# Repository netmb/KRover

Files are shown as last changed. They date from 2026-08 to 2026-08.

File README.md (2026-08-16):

# KRover

Dieses Projekt realisiert ein GNSS-RTK-Rover-System für rund 150 €.

KRover dient zur Anzeige von Flurstücken, zur Navigation zu Grenzpunkten und
zur Aufnahme eigener Punkte, Strecken, Flächen und relativer Höhen. Das System
besteht aus einer nativen iOS-App und einem ESP32-S3-basierten Rover mit
Quectel-LG290P-Empfänger und Neigungssensor.

Die App lädt Karten- und Flurstücksdaten, empfängt SAPOS-Korrekturdaten über
NTRIP und kommuniziert bidirektional per Bluetooth Low Energy (BLE) mit der
Rover-Hardware. RTCM-Korrekturen laufen von der App über BLE und UART zum
LG290P; GNSS-, IMU- und Statusdaten werden in Gegenrichtung an die App
übertragen.

<table>
  <tr>
    <td align="center" valign="top" width="33%">
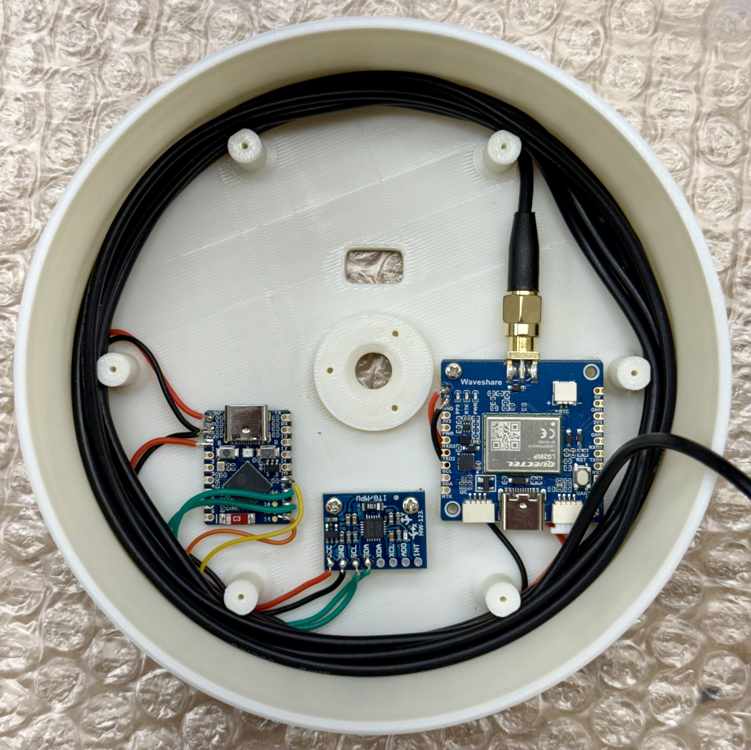
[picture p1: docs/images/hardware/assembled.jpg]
ESP32-S3-Zero, LG290P und GY-521 im KRover-Gehäuse
      
    </td>
    <td align="center" valign="top" width="33%">
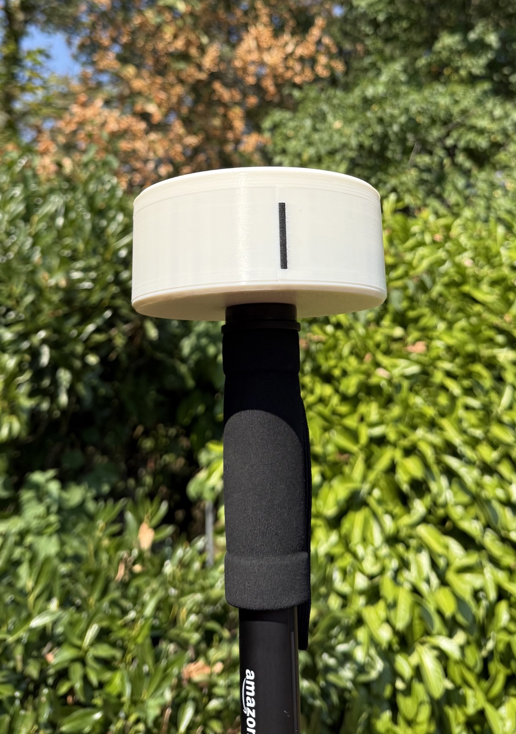
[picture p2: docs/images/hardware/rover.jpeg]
Fertiger KRover auf einem Einhandstativ
      
    </td>
    <td align="center" valign="top" width="33%">
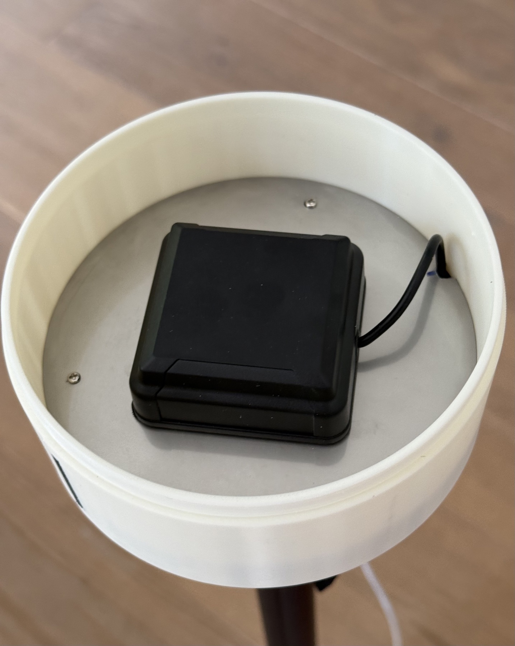
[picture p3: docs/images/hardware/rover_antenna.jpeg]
Mehrband-GNSS-Antenne im geöffneten KRover-Gehäuse
      
    </td>
  </tr>
</table>

<p align="center">
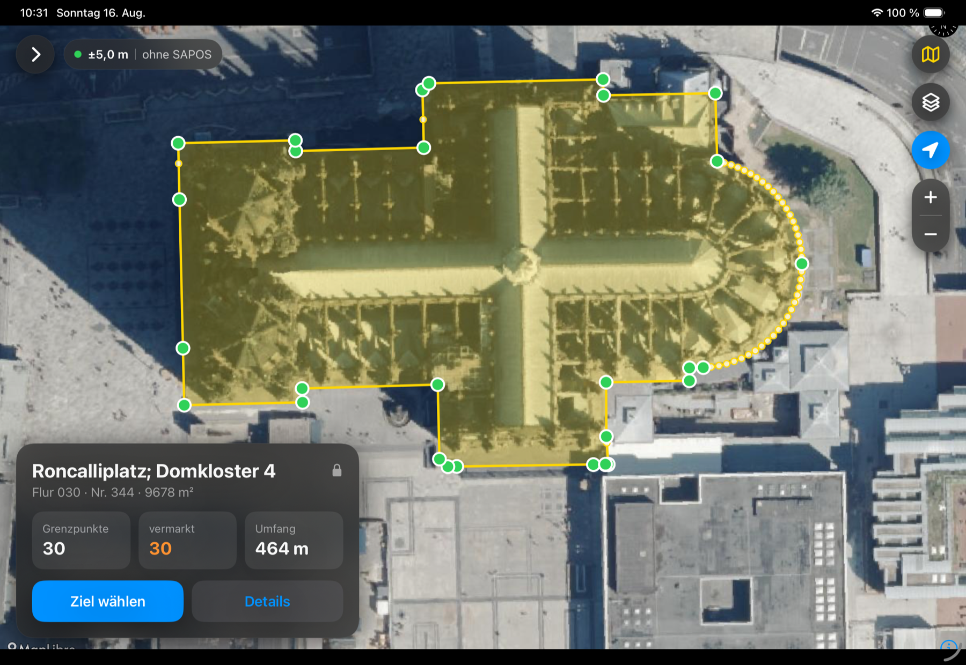
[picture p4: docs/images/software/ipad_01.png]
Flurstücksansicht der KRover-App auf einem iPad
  
</p>
<p align="center">
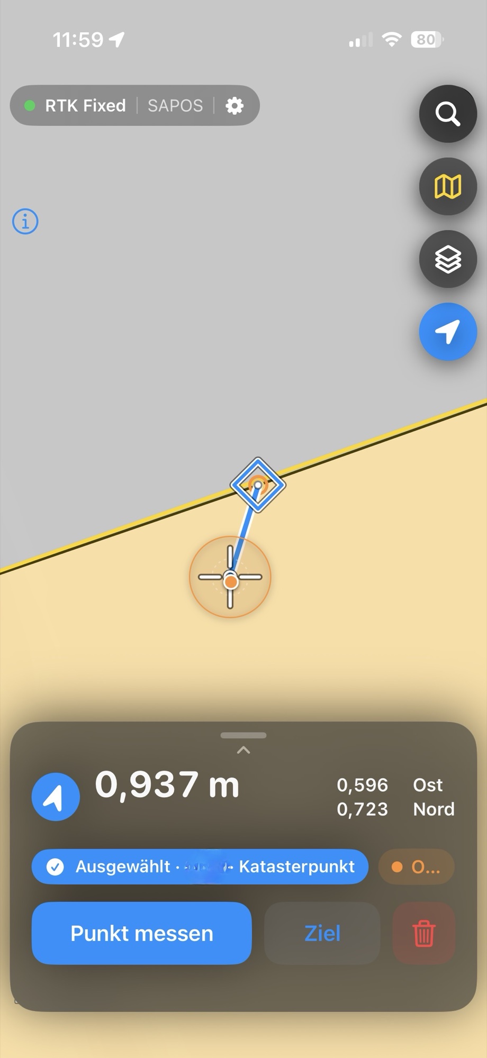
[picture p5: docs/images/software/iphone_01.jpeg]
Navigation zu einem Katasterpunkt in der KRover-App
  
  &nbsp;&nbsp;&nbsp;
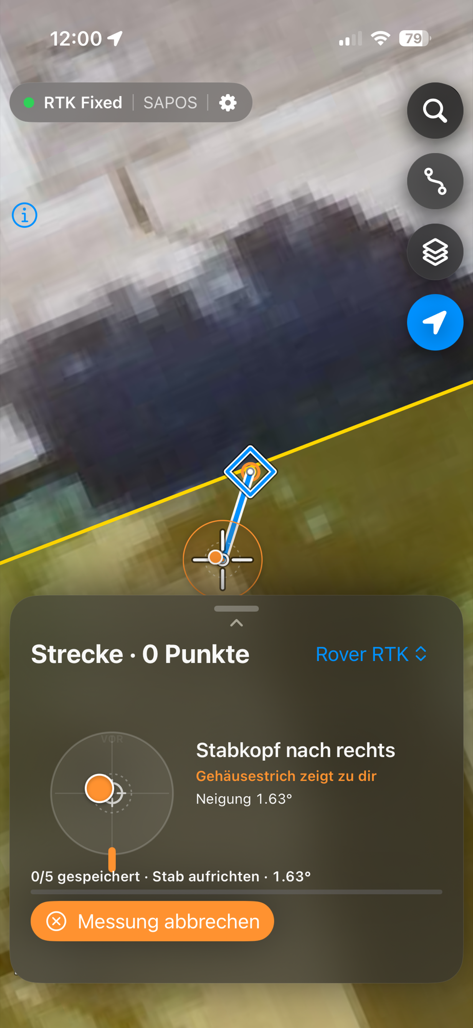
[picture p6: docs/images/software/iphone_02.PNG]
Streckenmessung mit Neigungsführung in der KRover-App
  
</p>

## Benötigte Hardware

<table>
  <tr>
    <td align="center" width="33%">
      <strong>ESP</strong><br>
      Waveshare ESP32-S3-Zero<br><br>
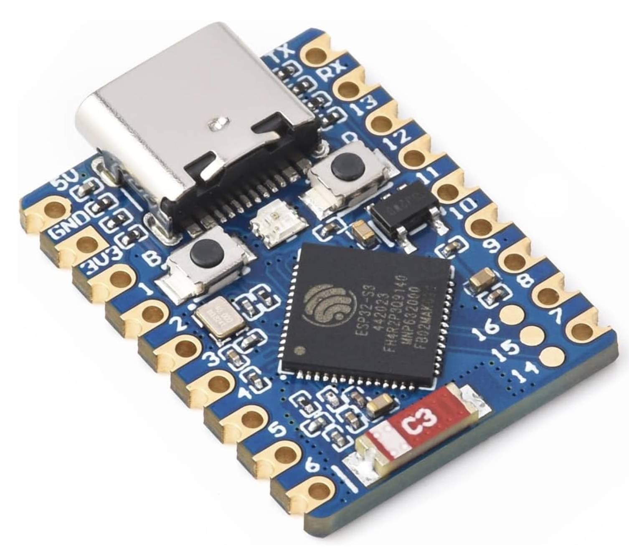
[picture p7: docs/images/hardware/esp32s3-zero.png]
Waveshare ESP32-S3-Zero
      
    </td>
    <td align="center" width="33%">
      <strong>GNSS-Empfänger</strong><br>
      Waveshare LG290P<br>mit Quectel LG290P<br><br>
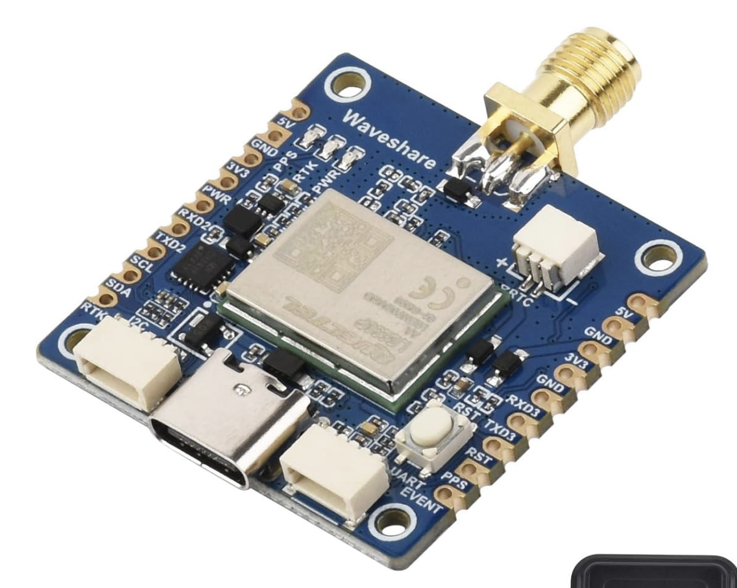
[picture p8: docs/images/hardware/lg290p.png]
Waveshare LG290P
      
    </td>
    <td align="center" width="33%">
      <strong>GNSS-Antenne</strong><br>
      GPS L1/L2/L5 · BeiDou B1C/B2a/B3<br>
      GLONASS G1/G2/G3 · Galileo E1/E5/E6<br>
      QZSS · SBAS<br><br>
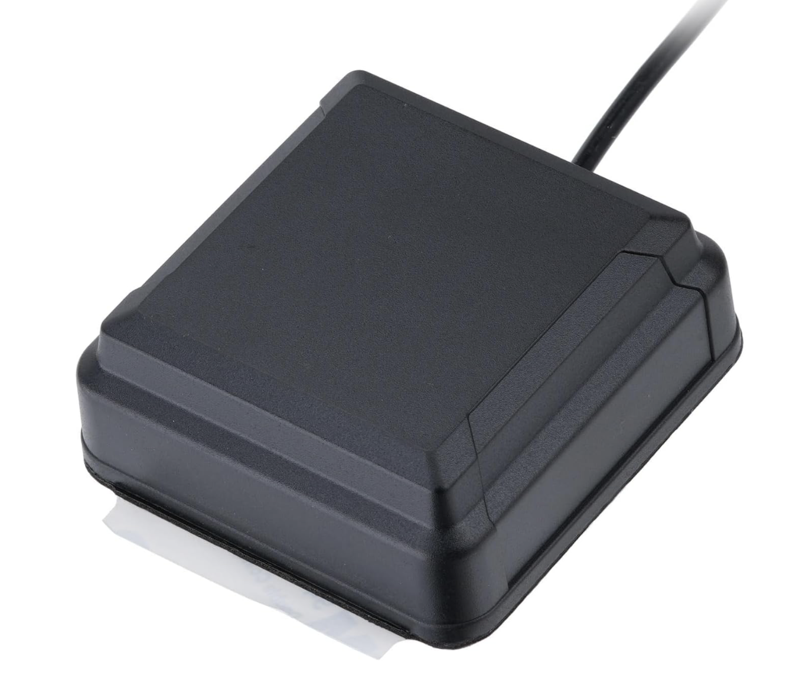
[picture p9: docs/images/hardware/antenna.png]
Aktive Mehrband-GNSS-Antenne
      
    </td>
  </tr>
  <tr>
    <td align="center" width="33%">
      <strong>Neigungssensor</strong><br>
      GY-521 mit MPU-6050<br><br>
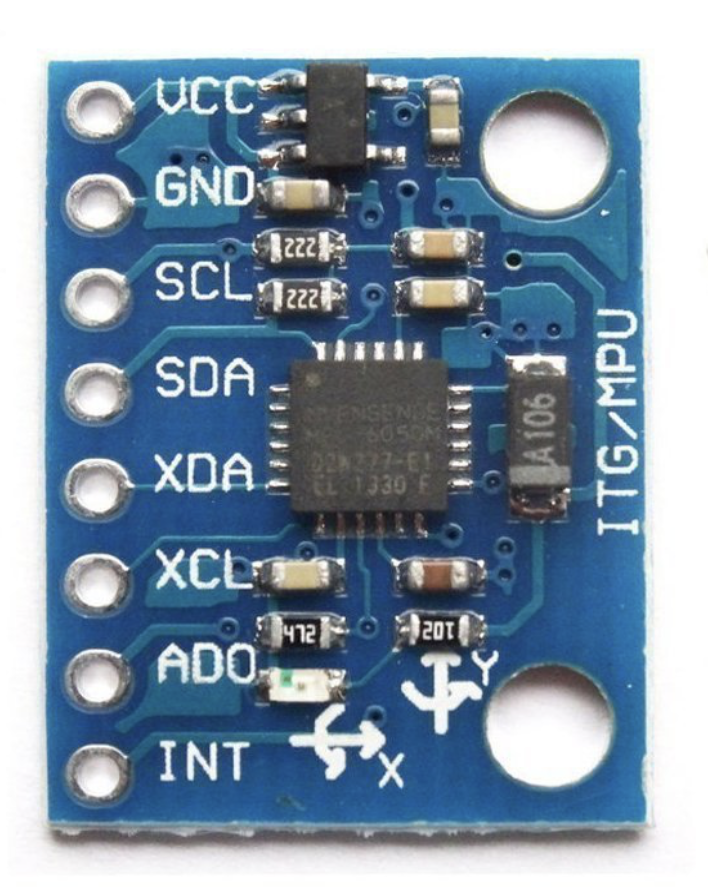
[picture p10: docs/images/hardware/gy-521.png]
GY-521 mit MPU-6050
      
    </td>
    <td align="center" width="33%">
      <strong>Einhandstativ</strong><br>
      1/4-Zoll-Standard-Fotogewinde<br>mit Schraubplatte<br><br>
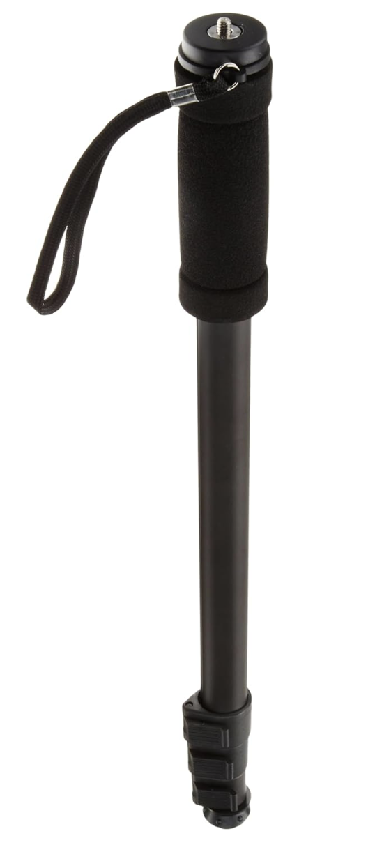
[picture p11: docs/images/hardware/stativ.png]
Einhandstativ
      
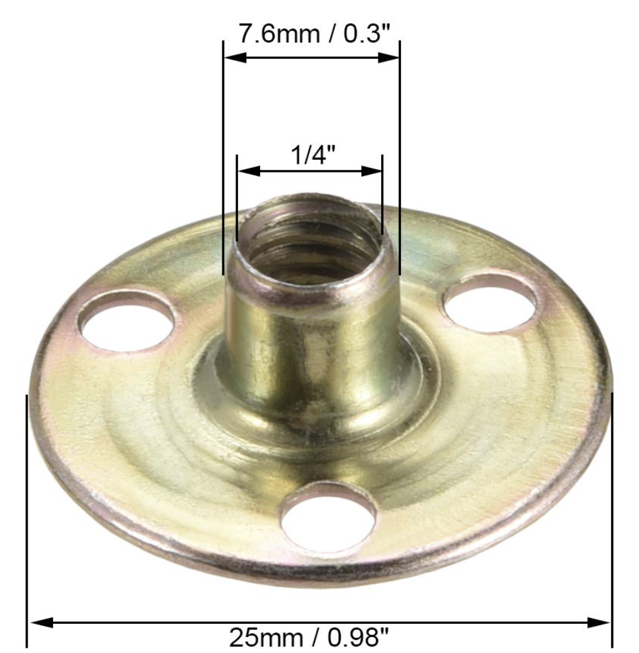
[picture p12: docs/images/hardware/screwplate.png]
Schraubplatte mit 1/4-Zoll-Gewinde
      
    </td>
    <td align="center" width="33%">
      <strong>Stahl-/Edelstahlronde</strong><br>
      1 mm Stärke<br>
      120 mm Durchmesser<br><br>
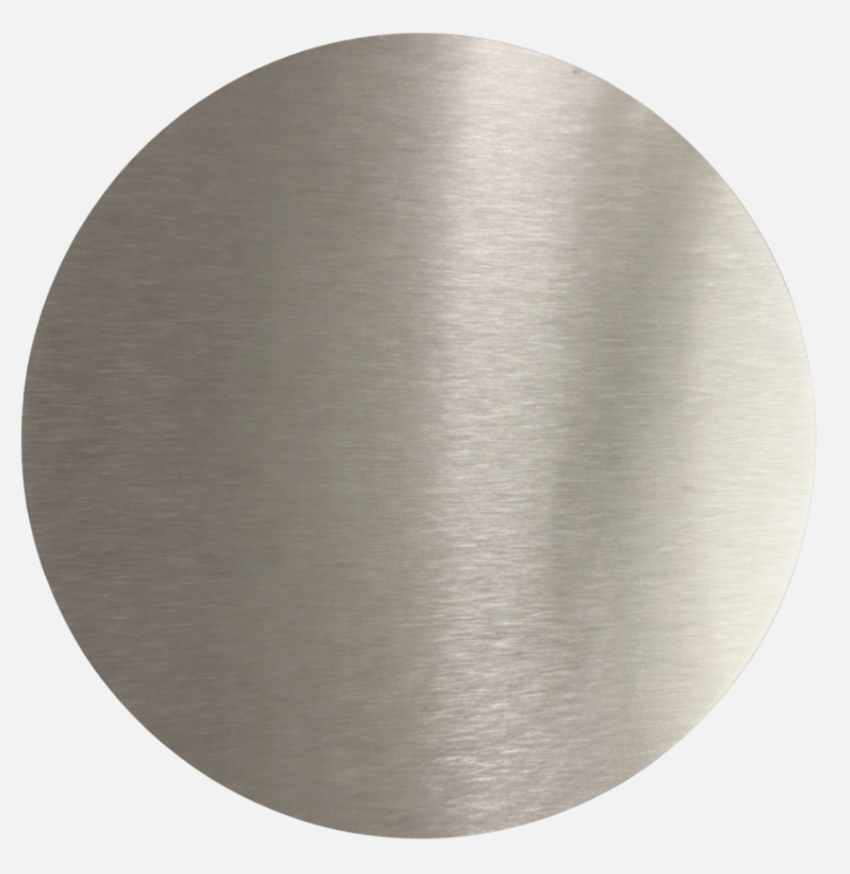
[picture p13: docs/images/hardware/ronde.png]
Stahl- oder Edelstahlronde
      
    </td>
  </tr>
</table>

Die Druckdatei für das Gehäuse liegt unter
[`case/case.3mf`](case/case.3mf).

## Hardware anschließen

### GY-521 mit ESP32-S3 verbinden

| GY-521 | ESP32-S3-Zero | Funktion |
|---|---|---|
| `VCC` | `3V3` | Versorgung mit 3,3 V |
| `GND` | `GND` | Gemeinsame Masse |
| `SDA` | `GPIO 8` | I²C-Daten |
| `SCL` | `GPIO 9` | I²C-Takt |

Die Firmware erkennt den MPU-6050 an `0x68` oder `0x69`. Wird kein Sensor
gefunden, aktiviert sie automatisch den integrierten IMU-Simulator.

### LG290P mit ESP32-S3 verbinden

| LG290P | ESP32-S3-Zero | Funktion |
|---|---|---|
| `TX` | `GPIO 7` (`RX`) | NMEA-/PQTM-Daten vom LG290P |
| `RX` | `GPIO 10` (`TX`) | RTCM-Korrekturdaten zum LG290P |
| `GND` | `GND` | Gemeinsame Masse |

Die UART-Verbindung verwendet `460800 Baud`, `8N1`.

## Repository installieren

```sh
git clone https://github.com/netmb/KRover.git
cd KRover
```

## ESP32-Firmware installieren

### Voraussetzungen

- [PlatformIO Core](https://docs.platformio.org/en/latest/core/installation/index.html)
  oder Visual Studio Code mit der PlatformIO-Erweiterung
- Waveshare ESP32-S3-Zero und ein USB-Datenkabel
- angeschlossene Rover-Hardware gemäß den Tabellen oben

### Firmware bauen und übertragen

1. ESP32-S3-Zero per USB mit dem Mac oder PC verbinden.
2. In das Firmware-Verzeichnis wechseln.
3. Firmware bauen und auf das Board übertragen.
4. Den seriellen Monitor öffnen und den Start kontrollieren.

```sh
cd firmware
pio run -e waveshare-esp32-s3-zero
pio run -e waveshare-esp32-s3-zero -t upload
pio device monitor --baud 115200
```

Falls PlatformIO den Upload-Port nicht automatisch erkennt, kann er explizit
angegeben werden:

```sh
pio run -e waveshare-esp32-s3-zero -t upload \
  --upload-port /dev/cu.usbmodemXXXX
```

Nach erfolgreichem Start erscheint der Rover als BLE-Gerät `KRover-XXXX`. Die
letzten vier Zeichen werden aus der MAC-Adresse des ESP32 gebildet. Die aktuelle
Konfiguration in [`firmware/platformio.ini`](firmware/platformio.ini) verwendet
den echten LG290P (`KATASTER_GNSS_SIMULATION=0`).

### Firmware testen

```sh
cd firmware
pio test -e native
pio run -e waveshare-esp32-s3-zero
```

## iOS-App installieren

### Voraussetzungen

- macOS mit Xcode 26 oder neuer
- [XcodeGen](https://github.com/yonaskolb/XcodeGen)
- iPhone oder iPad mit iOS 17 oder neuer
- Apple-Development-Team für die Installation auf einem echten Gerät

XcodeGen kann beispielsweise mit Homebrew installiert werden:

```sh
brew install xcodegen
```

### Xcode-Projekt erzeugen

Das Xcode-Projekt wird aus [`ios/project.yml`](ios/project.yml) generiert und
nicht im Repository gespeichert:

```sh
cd ios
xcodegen generate
open KRover.xcodeproj
```

### App auf iPhone oder iPad installieren

1. In Xcode das Projekt `KRover` und das Target `KRover` auswählen.
2. Unter **Signing & Capabilities** das eigene Development-Team eintragen.
3. Das angeschlossene iPhone oder iPad als Zielgerät auswählen.
4. Das Scheme `KRover` starten (`⌘R`).
5. Auf dem Gerät den Zugriff auf Bluetooth und den Standort erlauben.
6. In der App den Rover `KRover-XXXX` auswählen und verbinden.
7. SAPOS-Zugangsdaten in der App hinterlegen und die NTRIP-Verbindung starten.

SAPOS-Zugangsdaten werden im iOS-Schlüsselbund gespeichert. Ein physisches
iPhone oder iPad ist für die BLE-Verbindung erforderlich; der iOS-Simulator
kann für UI-Entwicklung und Tests verwendet werden.

Falls die Bundle-ID mit dem eigenen Development-Team kollidiert, muss
`PRODUCT_BUNDLE_IDENTIFIER` in [`ios/project.yml`](ios/project.yml) angepasst
und das Projekt anschließend erneut mit `xcodegen generate` erzeugt werden.

### iOS-Tests ausführen

```sh
cd ios
xcodegen generate
xcodebuild -project KRover.xcodeproj \
  -scheme KRover \
  -destination 'platform=iOS Simulator,name=iPhone 17 Pro' \
  test
```

Die Tests mit dem live NRW-Katasterdienst werden ohne fest eingechecktes
Flurstück übersprungen. Für einen lokalen Integrationstest kann ein eigenes
Test-Flurstück ausschließlich für den Prozess gesetzt werden:

```sh
KROVER_INTEGRATION_PARCEL_ID='...' xcodebuild -project KRover.xcodeproj \
  -scheme KRover \
  -destination 'platform=iOS Simulator,name=iPhone 17 Pro' \
  test
```

Das BLE-Datenformat und die verwendeten Characteristics sind in
[`docs/ble-protocol.md`](docs/ble-protocol.md) dokumentiert.

## Lizenz

KRover ist unter der
[PolyForm Noncommercial License 1.0.0](LICENSE) verfügbar. Private und andere
nichtkommerzielle Nutzung ist im Rahmen dieser Lizenz erlaubt. Kommerzielle
oder gewerbliche Nutzung erfordert vorab eine separate schriftliche Lizenz von
[`netmb`](https://github.com/netmb).

Das Projekt ist damit öffentlich einsehbar (source available), aber keine Open-
Source-Software im Sinne der OSI-Definition.

Abhängigkeiten und sonstiges Material Dritter sind davon ausgenommen und
behalten ihre jeweiligen Lizenzen. Details stehen in den
[Drittanbieter-Hinweisen](THIRD_PARTY_NOTICES.md). Bei der Weitergabe
kompilierter App- oder Firmware-Binaries müssen zusätzlich die dort genannten
Lizenzbedingungen erfüllt werden.

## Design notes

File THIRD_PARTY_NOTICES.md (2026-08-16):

# Drittanbieter-Hinweise

Die PolyForm-Noncommercial-Lizenz von KRover gilt nicht für Software und
sonstiges Material Dritter. Diese Bestandteile behalten ihre eigenen Lizenzen.
Das Repository enthält keine Kopien der nachfolgend genannten Bibliotheken;
sie werden beim Build über Swift Package Manager beziehungsweise PlatformIO
bezogen.

## Laufzeit-Abhängigkeiten

- **MapLibre Native 6.28.0** — BSD 2-Clause. Copyright MapLibre contributors,
  MapTiler.com und Mapbox. Die Lizenz und die Copyright-Hinweise müssen bei der
  Weitergabe der iOS-App in der Dokumentation oder in anderen mitgelieferten
  Materialien erhalten bleiben.
  [Lizenz](https://github.com/maplibre/maplibre-gl-native-distribution/blob/6.28.0/LICENSE.md)
- **NimBLE-Arduino 2.5.1** — Apache License 2.0. Copyright Ryan Powell sowie die
  Mitwirkenden von esp-nimble-cpp und NimBLE-Arduino; Teile gehen auf Neil
  Kolban und esp32-snippets zurück. Bei einer Firmware-Weitergabe sind die
  Apache-Lizenz und die NOTICE-Hinweise beizulegen.
  [Lizenz](https://github.com/h2zero/NimBLE-Arduino/blob/2.5.1/LICENSE) ·
  [NOTICE](https://github.com/h2zero/NimBLE-Arduino/blob/2.5.1/NOTICE)
- **Arduino-ESP32 2.0.17** — GNU Lesser General Public License 2.1 oder später.
  Die Version wird durch `espressif32@7.0.1` von PlatformIO bereitgestellt.
  Wer ein kompiliertes Firmware-Image verteilt, muss insbesondere die
  Lizenzhinweise, den zugehörigen Bibliotheks-Quellcode und eine praktisch
  nutzbare Möglichkeit zum Ändern und erneuten Linken der LGPL-Bestandteile
  bereitstellen. Die Rechte an diesen Bestandteilen dürfen durch die
  KRover-Lizenz nicht eingeschränkt werden.
  [Lizenz](https://github.com/espressif/arduino-esp32/blob/2.0.17/LICENSE.md)
- **PlatformIO Espressif 32 Platform 7.0.1** — Apache License 2.0.
  [Lizenz](https://github.com/platformio/platform-espressif32/blob/v7.0.1/LICENSE)

NimBLE-Arduino enthält seinerseits weitere Bestandteile, unter anderem den
Apache-2.0-lizenzierten NimBLE-Stack und BSD-lizenzierte TinyCrypt-Komponenten.
Die jeweiligen Lizenzdateien der beim Build aufgelösten Pakete sind ebenfalls
zu beachten.

## Nur für Tests

- **Unity 2.6.1** — MIT License. Unity wird nur von den nativen Firmware-Tests
  verwendet und nicht in die Geräte-Firmware eingebunden.
  [Lizenz](https://github.com/ThrowTheSwitch/Unity/blob/v2.6.1/LICENSE.txt)

## Apple-Plattformbibliotheken

Die iOS-App verwendet außerdem Frameworks aus dem Apple SDK. Deren Nutzung und
Weitergabe richtet sich nach den jeweils anwendbaren Apple-Bedingungen; sie
werden durch dieses Repository nicht neu lizenziert.

## Bild- und Markenrechte

Bilder, Produktdarstellungen, Logos und Marken Dritter werden nicht durch die
KRover-Lizenz freigegeben. Vor einer Weiterverwendung oder Veröffentlichung
müssen die jeweils erforderlichen Rechte separat geprüft werden.

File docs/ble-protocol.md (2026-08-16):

# KRover BLE protocol

Protocol version: **1**

The BLE service carries two ordered byte streams plus status and control. The
GNSS and RTCM payloads are not modified. A small transport header detects
session changes and missing BLE writes/notifications.

## UUIDs

| Purpose | UUID | Direction | GATT properties |
|---|---|---|---|
| Service | `7A1E0001-9B6D-4C7A-8F21-6D3E5C790001` | — | — |
| RTCM RX | `7A1E0002-9B6D-4C7A-8F21-6D3E5C790001` | iOS → ESP | Write, Write Without Response |
| GNSS TX | `7A1E0003-9B6D-4C7A-8F21-6D3E5C790001` | ESP → iOS | Notify |
| Status | `7A1E0004-9B6D-4C7A-8F21-6D3E5C790001` | ESP → iOS | Read, Notify |
| Control | `7A1E0005-9B6D-4C7A-8F21-6D3E5C790001` | iOS → ESP | Write |
| IMU TX | `7A1E0006-9B6D-4C7A-8F21-6D3E5C790001` | ESP → iOS | Read, Notify |

## Stream packet

Every value written to RTCM RX or notified on GNSS TX begins with this
four-byte header:

| Offset | Size | Field |
|---:|---:|---|
| 0 | 1 | Protocol version (`1`) |
| 1 | 1 | Session identifier |
| 2 | 2 | Unsigned sequence, little-endian |
| 4 | n | Unmodified stream payload |

Sequence numbers wrap modulo 65536. A new session identifier resets the
expected sequence and all partial stream parsers. A sequence gap causes the
receiver to discard its partial NMEA sentence or RTCM frame and resynchronise.

The sender determines the maximum payload at runtime from the negotiated ATT
write/notification size. No fixed MTU is assumed.

## RTCM rules

- iOS parses and CRC24Q-validates RTCM 3 before enqueueing it for BLE.
- ESP parses the received stream again.
- ESP only passes complete CRC-valid RTCM frames to the active `RtcmSink`.
- Partial data is never replayed after a reconnect.
- Corrections are live data. Queues are bounded and stale data is discarded.

RTCM RX normally uses Write Without Response. iOS obeys both CoreBluetooth's
`canSendWriteWithoutResponse` signal and the `free` capacity reported by ESP.

## GNSS rules

GNSS TX carries complete or partial NMEA/PQTM byte streams. The iOS parser
reassembles lines using CR/LF delimiters and validates NMEA checksums. A
sequence gap clears the partial line buffer.

## Status payload

Status is compact UTF-8 JSON so that it remains readable in generic BLE tools.

```json
{"v":1,"m":"walk","rb":12345,"rf":37,"rc":0,"sg":0,"qd":0,"free":18,"age":180}
```

| Key | Meaning |
|---|---|
| `v` | Protocol version |
| `m` | Dummy GNSS mode |
| `rb` | RTCM payload bytes accepted |
| `rf` | Valid RTCM frames |
| `rc` | RTCM CRC errors |
| `sg` | BLE sequence gaps |
| `qd` | RTCM packets dropped because the ESP queue was full |
| `free` | Free RTCM packet slots in the ESP queue |
| `age` | Milliseconds since the most recent valid RTCM frame, `-1` if none |

## Control payload

Control is UTF-8 JSON written with response.

```json
{"mode":"static"}
{"mode":"walk"}
{"mode":"quality"}
{"resetStats":true}
```

Unknown commands are ignored. Control never shares a characteristic with the
GNSS or RTCM byte streams.

IMU commands use the same control characteristic:

```json
{"imuMode":"level"}
{"imuMode":"tilted"}
{"imuMode":"motion"}
{"imuMode":"left"}
{"imuMode":"right"}
{"imuMode":"forward"}
{"imuMode":"backward"}
{"calibrateImu":true}
{"calibrateImuDirection":true}
{"resetImuCalibration":true}
```

The `imuMode` values only affect the simulator. The four directional values
name the correction shown to the operator and exercise the marker-relative
visual and acoustic guidance without physical IMU hardware. `calibrateImu`
collects 125 consecutive stationary samples (about 2.5 seconds) while the pole
is vertical, stores the vertical zero, and finishes. The independent
`calibrateImuDirection` command then reports `q=aligning` and collects 30
stationary samples (about 0.6 seconds) while the pole top is tilted 3–20 degrees
toward the housing marker; 5–15 degrees is the recommended target. Up to five
rejected samples are tolerated after collection begins before progress is
reset. This separate action determines the fixed sensor-to-marker angle; a
vertical pole cannot provide that direction. The command is rejected until a
vertical calibration exists. Both results are stored in ESP32 NVS and normally
remain valid for the lifetime of the unchanged mechanical assembly.

## IMU telemetry

IMU TX sends compact JSON at 10 Hz. It is deliberately separate from transport
status so the orientation update rate does not increase RTCM control traffic.

```json
{"v":1,"s":"simulation","x":true,"r":0.03,"p":-0.02,"t":0.04,"k":-90.0,"a":1.0000,"g":0.02,"m":false,"l":true,"o":true,"c":true,"y":true,"q":"ready","n":50,"u":true,"d":4,"h":810,"e":3}
```

| Key | Meaning |
|---|---|
| `s` | `simulation` or `mpu6050` |
| `x` | Values are simulated and must be labelled as a test mode |
| `r`, `p`, `t` | Roll, pitch and total pole tilt in degrees |
| `k` | Housing-marker direction in the sensor `(pitch, roll)` plane, in degrees |
| `a` | Acceleration vector magnitude in g |
| `g` | Angular rate magnitude in degrees per second |
| `m` | Pole is moving |
| `l` | Calibrated tilt is at most 0.5 degrees |
| `o` | Fully calibrated, within 0.5 degrees and stationary for at least 400 ms |
| `c` | Vertical zero calibration is valid |
| `y` | Operator-relative direction calibration is valid |
| `q`, `n` | Active calibration (`required`, `calibrating`, `aligning`, `ready`) and samples in that action |
| `u`, `d` | Sensor availability and sample age in milliseconds |
| `h` | Milliseconds continuously held level and stationary |
| `e` | Counter incremented whenever a new measurement-ready window begins |

Fields `k`, `y`, `h` and `e` were appended without increasing the protocol version.
The iOS decoder therefore treats them as optional when talking to older
firmware; an absent `k` uses the documented -90-degree marker mounting.

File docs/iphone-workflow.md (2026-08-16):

# iPhone development workflow

## Physical-device screenshots on iOS 26

Use Xcode's current CoreDevice screenshot path. `idevicescreenshot` does not
work reliably with the personalized Developer Disk Image used by iOS 26.

1. Open `ios/KRover.xcodeproj` in Xcode.
2. Open **Window → Devices and Simulators** (`Shift-Command-2`).
3. Select the connected iPhone (`i16P`).
4. Click **Take Screenshot**.
5. Xcode saves the PNG as `~/Desktop/Screenshot YYYY-MM-DD at HH.MM.SS.png`.

For the currently installed Xcode, the click can be automated with:

```sh
osascript <<'APPLESCRIPT'
tell application "Xcode" to activate
tell application "System Events"
  tell process "Xcode"
    set deviceWindows to every window whose name is "Devices"
    if (count of deviceWindows) is 0 then
      keystroke "2" using {command down, shift down}
      delay 3
    end if
    click button "Take Screenshot" of UI element 1 of UI element 7 of UI element 1 of window "Devices"
  end tell
end tell
APPLESCRIPT
```

Wait several seconds before selecting the newest matching PNG; Xcode writes it
asynchronously.

```sh
find "$HOME/Desktop" -maxdepth 1 -type f -name 'Screenshot *.png' -mmin -2 -print0 \
  | xargs -0 ls -1t | head -1
```

The UI-element indexes are specific to the present Xcode Devices window. If a
future Xcode changes the hierarchy, inspect the accessibility tree and locate
the button whose name is `Take Screenshot`.

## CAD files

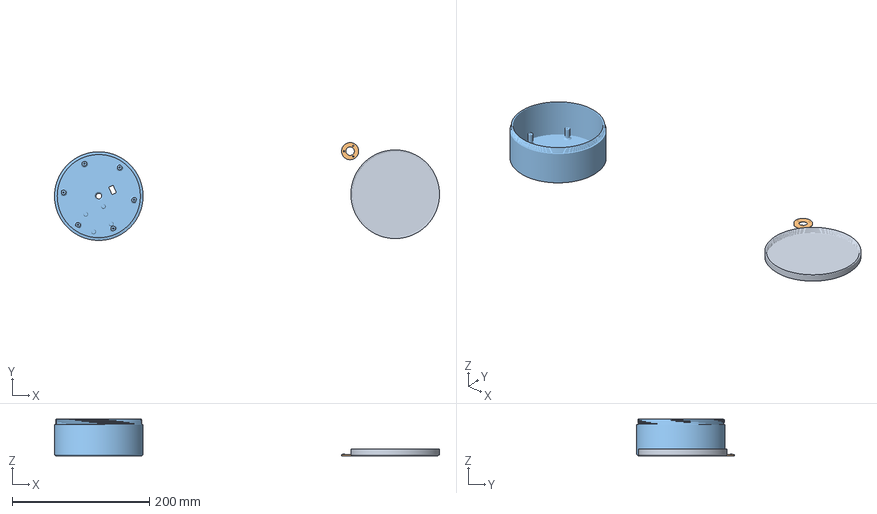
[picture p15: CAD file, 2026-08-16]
case/case.3mf
560.6 x 142.4 x 53.5 mm
Deckel.stl
flanschplatte.stl
Base

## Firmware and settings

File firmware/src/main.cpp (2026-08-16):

#include <Arduino.h>
#include <NimBLEDevice.h>
#include <Preferences.h>

#include <algorithm>
#include <cmath>
#include <cstdio>
#include <cstring>
#include <string>

#include "freertos/FreeRTOS.h"
#include "freertos/queue.h"
#include "imu_processor.h"
#include "imu_source.h"
#include "rtcm_parser.h"
#include "transport_protocol.h"

#ifndef KATASTER_IMU_SDA
#define KATASTER_IMU_SDA 8
#endif

#ifndef KATASTER_IMU_SCL
#define KATASTER_IMU_SCL 9
#endif

#ifndef KATASTER_LG290P_RX
#define KATASTER_LG290P_RX 7
#endif

#ifndef KATASTER_LG290P_TX
#define KATASTER_LG290P_TX 10
#endif

#ifndef KATASTER_LG290P_BAUD
#define KATASTER_LG290P_BAUD 460800
#endif

#ifndef KATASTER_GNSS_SIMULATION
#define KATASTER_GNSS_SIMULATION 0
#endif

namespace {

constexpr std::size_t kMaximumBleValue = 512;
constexpr std::size_t kRtcmQueueDepth = 20;
constexpr std::size_t kGnssPayloadSize = 160;
constexpr uint32_t kImuCalibrationMagic = 0x4B494D34U;  // KIM4

struct StoredImuCalibration {
  uint32_t magic = kImuCalibrationMagic;
  kataster::ImuCalibration calibration;
};

struct BlePacket {
  uint16_t length = 0;
  uint8_t bytes[kMaximumBleValue]{};
};

struct TransportStats {
  uint32_t rtcmBytes = 0;
  uint32_t rtcmFrames = 0;
  uint32_t rtcmCrcErrors = 0;
  uint32_t sequenceGaps = 0;
  uint32_t queueDrops = 0;
  uint32_t lastValidRtcmMs = 0;
  bool hasValidRtcm = false;
};

enum class DummyMode { kStatic, kWalk, kQuality };

QueueHandle_t rtcmQueue = nullptr;
NimBLECharacteristic* gnssCharacteristic = nullptr;
NimBLECharacteristic* statusCharacteristic = nullptr;
NimBLECharacteristic* controlCharacteristic = nullptr;
NimBLECharacteristic* imuCharacteristic = nullptr;

portMUX_TYPE statsMux = portMUX_INITIALIZER_UNLOCKED;
TransportStats transportStats;
volatile bool bleConnected = false;
volatile DummyMode dummyMode = DummyMode::kWalk;
volatile kataster::SimulatedImuMode requestedImuMode =
    kataster::SimulatedImuMode::kLevel;
volatile bool imuCalibrationRequested = false;
volatile bool imuDirectionCalibrationRequested = false;
volatile bool imuCalibrationResetRequested = false;
volatile bool imuHardwarePresent = false;
volatile uint32_t imuHardwareSamples = 0;
volatile uint32_t lg290pRxBytes = 0;
volatile uint32_t lg290pValidNmeaSentences = 0;

kataster::Mpu6050Source mpu6050(Wire, KATASTER_IMU_SDA, KATASTER_IMU_SCL);
kataster::SimulatedImuSource simulatedImu;
HardwareSerial lg290pSerial(1);

uint8_t gnssSession = 1;
uint16_t gnssSequence = 0;

const char* modeName(DummyMode mode) {
  switch (mode) {
    case DummyMode::kStatic:
      return "static";
    case DummyMode::kQuality:
      return "quality";
    case DummyMode::kWalk:
    default:
      return "walk";
  }
}

const char* gnssModeName() {
#if KATASTER_GNSS_SIMULATION
  return modeName(dummyMode);
#else
  return "lg290p";
#endif
}

void resetTransportStats() {
  portENTER_CRITICAL(&statsMux);
  transportStats = {};
  portEXIT_CRITICAL(&statsMux);
}

void onValidRtcmFrame(const uint8_t* frame, std::size_t length,
                      uint16_t messageType, void*) {
  portENTER_CRITICAL(&statsMux);
  ++transportStats.rtcmFrames;
  transportStats.lastValidRtcmMs = millis();
  transportStats.hasValidRtcm = true;
  portEXIT_CRITICAL(&statsMux);

#if !KATASTER_GNSS_SIMULATION
  const std::size_t written = lg290pSerial.write(frame, length);
  if (written != length) {
    Serial.printf("LG290P RTCM write incomplete: %u/%u bytes\n",
                  static_cast<unsigned>(written),
                  static_cast<unsigned>(length));
  }
#endif

  if ((transportStats.rtcmFrames % 25U) == 1U) {
    Serial.printf("RTCM valid: type=%u frames=%lu\n", messageType,
                  static_cast<unsigned long>(transportStats.rtcmFrames));
  }
}

class RoverServerCallbacks final : public NimBLEServerCallbacks {
  void onConnect(NimBLEServer*, NimBLEConnInfo&) override {
    bleConnected = true;
    ++gnssSession;
    gnssSequence = 0;
    Serial.println("BLE central connected");
  }

  void onDisconnect(NimBLEServer*, NimBLEConnInfo&, int reason) override {
    bleConnected = false;
    Serial.printf("BLE central disconnected, reason=%d\n", reason);
  }
};

class RtcmCallbacks final : public NimBLECharacteristicCallbacks {
  void onWrite(NimBLECharacteristic* characteristic,
               NimBLEConnInfo&) override {
    const NimBLEAttValue value = characteristic->getValue();
    if (value.size() < kataster::kStreamHeaderSize ||
        value.size() > kMaximumBleValue) {
      return;
    }

    BlePacket packet;
    packet.length = static_cast<uint16_t>(value.size());
    std::memcpy(packet.bytes, value.data(), value.size());
    if (xQueueSend(rtcmQueue, &packet, 0) != pdTRUE) {
      portENTER_CRITICAL(&statsMux);
      ++transportStats.queueDrops;
      portEXIT_CRITICAL(&statsMux);
    }
  }
};

class ControlCallbacks final : public NimBLECharacteristicCallbacks {
  void onWrite(NimBLECharacteristic* characteristic,
               NimBLEConnInfo&) override {
    const std::string value = characteristic->getValue();
    if (value.find("resetStats") != std::string::npos) {
      resetTransportStats();
      Serial.println("Transport statistics reset");
    }
    if (value.find("static") != std::string::npos) {
      dummyMode = DummyMode::kStatic;
    } else if (value.find("quality") != std::string::npos) {
      dummyMode = DummyMode::kQuality;
    } else if (value.find("walk") != std::string::npos) {
      dummyMode = DummyMode::kWalk;
    }
    if (value.find("imuMode") != std::string::npos) {
      if (value.find("forward") != std::string::npos) {
        requestedImuMode = kataster::SimulatedImuMode::kForward;
      } else if (value.find("backward") != std::string::npos) {
        requestedImuMode = kataster::SimulatedImuMode::kBackward;
      } else if (value.find("left") != std::string::npos) {
        requestedImuMode = kataster::SimulatedImuMode::kLeft;
      } else if (value.find("right") != std::string::npos) {
        requestedImuMode = kataster::SimulatedImuMode::kRight;
      } else if (value.find("tilted") != std::string::npos) {
        requestedImuMode = kataster::SimulatedImuMode::kTilted;
      } else if (value.find("motion") != std::string::npos) {
        requestedImuMode = kataster::SimulatedImuMode::kMotion;
      } else if (value.find("level") != std::string::npos) {
        requestedImuMode = kataster::SimulatedImuMode::kLevel;
      }
    }
    if (value.find("\"calibrateImuDirection\"") != std::string::npos) {
      imuDirectionCalibrationRequested = true;
    } else if (value.find("\"calibrateImu\"") != std::string::npos) {
      imuCalibrationRequested = true;
    }
    if (value.find("resetImuCalibration") != std::string::npos) {
      imuCalibrationResetRequested = true;
    }
  }
};

bool loadImuCalibration(Preferences& preferences, const char* key,
                        kataster::ImuCalibration& calibration) {
  if (preferences.getBytesLength(key) != sizeof(StoredImuCalibration)) {
    return false;
  }
  StoredImuCalibration stored;
  if (preferences.getBytes(key, &stored, sizeof(stored)) != sizeof(stored) ||
      stored.magic != kImuCalibrationMagic || !stored.calibration.valid) {
    return false;
  }
  calibration = stored.calibration;
  return true;
}

void saveImuCalibration(Preferences& preferences, const char* key,
                        const kataster::ImuCalibration& calibration) {
  StoredImuCalibration stored;
  stored.calibration = calibration;
  preferences.putBytes(key, &stored, sizeof(stored));
}

void publishImu(const kataster::ImuReading& reading, const char* source,
                bool simulation, uint32_t ageMilliseconds) {
  if (imuCharacteristic == nullptr) {
    return;
  }
  const bool available = ageMilliseconds < 500U;
  char json[380]{};
  std::snprintf(
      json, sizeof(json),
      "{\"v\":1,\"s\":\"%s\",\"x\":%s,\"r\":%.3f,\"p\":%.3f,"
      "\"t\":%.3f,\"k\":%.3f,\"a\":%.4f,\"g\":%.3f,\"m\":%s,\"l\":%s,"
      "\"o\":%s,\"c\":%s,\"y\":%s,\"q\":\"%s\",\"n\":%u,\"u\":%s,"
      "\"d\":%lu,\"h\":%lu,\"e\":%lu}",
      source, simulation ? "true" : "false", reading.rollDegrees,
      reading.pitchDegrees, reading.totalTiltDegrees,
      reading.markerDirectionDegrees,
      reading.accelerationMagnitudeG, reading.angularRateDps,
      reading.moving ? "true" : "false",
      reading.level ? "true" : "false",
      reading.measurementReady ? "true" : "false",
      reading.calibrated ? "true" : "false",
      reading.directionCalibrated ? "true" : "false",
      kataster::calibrationStateName(reading.calibrationState),
      reading.calibrationSamples, available ? "true" : "false",
      static_cast<unsigned long>(ageMilliseconds),
      static_cast<unsigned long>(reading.stableMilliseconds),
      static_cast<unsigned long>(reading.readySequence));
  imuCharacteristic->setValue(json);
  if (bleConnected) {
    imuCharacteristic->notify();
  }
}

void imuTask(void*) {
  kataster::ImuSource* source = nullptr;
  if (mpu6050.begin()) {
    source = &mpu6050;
    imuHardwarePresent = true;
    Serial.printf("GY-521 detected: MPU-6050 at 0x%02X, SDA=%d, SCL=%d\n",
                  mpu6050.address(), KATASTER_IMU_SDA, KATASTER_IMU_SCL);
  } else {
    simulatedImu.begin();
    source = &simulatedImu;
    Serial.printf(
        "No MPU-6050 detected on SDA=%d/SCL=%d; IMU simulator active\n",
        KATASTER_IMU_SDA, KATASTER_IMU_SCL);
  }

  Preferences preferences;
  preferences.begin("kataster-imu", false);
  const char* calibrationKey = source->isSimulation() ? "sim-cal" : "mpu-cal";
  kataster::ImuProcessor processor;
  kataster::ImuCalibration storedCalibration;
  if (loadImuCalibration(preferences, calibrationKey, storedCalibration)) {
    processor.setCalibration(storedCalibration);
    Serial.printf("IMU calibration loaded for %s (direction=%s)\n",
                  source->name(),
                  storedCalibration.markerValid ? "calibrated" : "required");
  }

  kataster::ImuReading latest;
  uint32_t lastSampleMs = 0;
  uint32_t lastPublishMs = 0;
  while (true) {
    if (source->isSimulation()) {
      simulatedImu.setMode(requestedImuMode);
    }
    if (imuCalibrationResetRequested) {
      imuCalibrationResetRequested = false;
      processor.resetCalibration();
      preferences.remove(calibrationKey);
      Serial.println("IMU calibration reset");
    }
    if (imuCalibrationRequested) {
      imuCalibrationRequested = false;
      processor.beginCalibration();
      Serial.println("IMU vertical calibration started; hold pole still and vertical");
    }
    if (imuDirectionCalibrationRequested) {
      imuDirectionCalibrationRequested = false;
      if (processor.beginDirectionCalibration()) {
        Serial.println(
            "IMU direction calibration started; tilt pole top 3-20 degrees "
            "toward the housing marker");
      } else {
        Serial.println(
            "IMU direction calibration rejected: vertical calibration required");
      }
    }

    kataster::ImuSample sample;
    if (source->read(sample)) {
      if (!source->isSimulation()) {
        ++imuHardwareSamples;
      }
      latest = processor.update(sample);
      lastSampleMs = sample.timestampMs;
      if (processor.takeCalibrationCompleted()) {
        saveImuCalibration(preferences, calibrationKey,
                           processor.calibration());
        if (processor.calibration().markerValid) {
          Serial.printf(
              "IMU direction calibration completed and stored (marker=%.2f "
              "deg)\n",
              processor.calibration().markerDirectionDegrees);
        } else {
          Serial.printf(
              "IMU vertical calibration completed and stored (1g=%.4f g); "
              "direction calibration remains separate\n",
              processor.calibration().accelerationReferenceG);
        }
      }
    }

    const uint32_t now = millis();
    if (now - lastPublishMs >= 100U) {
      const uint32_t age = lastSampleMs == 0 ? UINT32_MAX : now - lastSampleMs;
      publishImu(latest, source->name(), source->isSimulation(), age);
      lastPublishMs = now;
    }
    vTaskDelay(pdMS_TO_TICKS(20));
  }
}

void rtcmTask(void*) {
  kataster::RtcmParser parser(onValidRtcmFrame);
  bool hasSession = false;
  uint8_t currentSession = 0;
  uint16_t expectedSequence = 0;
  uint32_t previousCrcErrors = 0;

  BlePacket packet;
  while (true) {
    if (xQueueReceive(rtcmQueue, &packet, portMAX_DELAY) != pdTRUE) {
      continue;
    }
    if (packet.length < kataster::kStreamHeaderSize ||
        packet.bytes[0] != kataster::kProtocolVersion) {
      continue;
    }

    const uint8_t session = packet.bytes[1];
    const uint16_t sequence = kataster::decodeSequence(packet.bytes);
    if (!hasSession || session != currentSession) {
      currentSession = session;
      expectedSequence = sequence;
      hasSession = true;
      parser.reset();
    }
    if (sequence != expectedSequence) {
      portENTER_CRITICAL(&statsMux);
      ++transportStats.sequenceGaps;
      portEXIT_CRITICAL(&statsMux);
      parser.reset();
    }
    expectedSequence = static_cast<uint16_t>(sequence + 1U);

    const std::size_t payloadLength =
        packet.length - kataster::kStreamHeaderSize;
    portENTER_CRITICAL(&statsMux);
    transportStats.rtcmBytes += static_cast<uint32_t>(payloadLength);
    portEXIT_CRITICAL(&statsMux);

    parser.feed(packet.bytes + kataster::kStreamHeaderSize, payloadLength);
    const uint32_t crcErrors = parser.crcErrors();
    if (crcErrors != previousCrcErrors) {
      portENTER_CRITICAL(&statsMux);
      transportStats.rtcmCrcErrors += crcErrors - previousCrcErrors;
      portEXIT_CRITICAL(&statsMux);
      previousCrcErrors = crcErrors;
    }
  }
}

uint8_t nmeaChecksum(const char* body) {
  uint8_t checksum = 0;
  while (*body != '\0') {
    checksum ^= static_cast<uint8_t>(*body++);
  }
  return checksum;
}

void notifyGnssBytes(const uint8_t* bytes, std::size_t length) {
  if (!bleConnected || gnssCharacteristic == nullptr) {
    return;
  }

  std::size_t offset = 0;
  while (offset < length) {
    const std::size_t payloadLength =
        std::min(kGnssPayloadSize, length - offset);
    uint8_t packet[kGnssPayloadSize + kataster::kStreamHeaderSize]{};
    kataster::encodeHeader(packet, gnssSession, gnssSequence++);
    std::memcpy(packet + kataster::kStreamHeaderSize, bytes + offset,
                payloadLength);
    if (!gnssCharacteristic->notify(packet,
                                    payloadLength +
                                        kataster::kStreamHeaderSize)) {
      break;
    }
    offset += payloadLength;
  }
}

void notifyNmeaBody(const char* body) {
  char sentence[196]{};
  std::snprintf(sentence, sizeof(sentence), "$%s*%02X\r\n", body,
                nmeaChecksum(body));
  notifyGnssBytes(reinterpret_cast<const uint8_t*>(sentence),
                  std::strlen(sentence));
}

int nmeaHexValue(char value) {
  if (value >= '0' && value <= '9') {
    return value - '0';
  }
  if (value >= 'A' && value <= 'F') {
    return value - 'A' + 10;
  }
  if (value >= 'a' && value <= 'f') {
    return value - 'a' + 10;
  }
  return -1;
}

bool hasValidNmeaChecksum(const char* sentence, std::size_t length) {
  if (sentence == nullptr || length < 7 || sentence[0] != '$') {
    return false;
  }

  uint8_t calculated = 0;
  std::size_t checksumPosition = 0;
  for (std::size_t index = 1; index < length; ++index) {
    if (sentence[index] == '*') {
      checksumPosition = index;
      break;
    }
    calculated ^= static_cast<uint8_t>(sentence[index]);
  }

  if (checksumPosition == 0 || checksumPosition + 2 >= length) {
    return false;
  }
  const int high = nmeaHexValue(sentence[checksumPosition + 1]);
  const int low = nmeaHexValue(sentence[checksumPosition + 2]);
  return high >= 0 && low >= 0 &&
         calculated == static_cast<uint8_t>((high << 4) | low);
}

void lg290pGnssTask(void*) {
  uint8_t buffer[256]{};
  bool receptionAnnounced = false;
  bool validNmeaAnnounced = false;
  char sentence[192]{};
  std::size_t sentenceLength = 0;

  while (true) {
    const int available = lg290pSerial.available();
    if (available <= 0) {
      vTaskDelay(pdMS_TO_TICKS(2));
      continue;
    }

    const std::size_t requested =
        std::min<std::size_t>(static_cast<std::size_t>(available),
                              sizeof(buffer));
    std::size_t received = 0;
    while (received < requested) {
      const int value = lg290pSerial.read();
      if (value < 0) {
        break;
      }
      buffer[received++] = static_cast<uint8_t>(value);
    }

    if (received > 0) {
      lg290pRxBytes += static_cast<uint32_t>(received);
      if (!receptionAnnounced) {
        receptionAnnounced = true;
        Serial.println("LG290P UART data received");
      }
      for (std::size_t index = 0; index < received; ++index) {
        const char value = static_cast<char>(buffer[index]);
        if (value == '$') {
          sentence[0] = value;
          sentenceLength = 1;
        } else if (sentenceLength > 0 && value == '\n') {
          sentence[sentenceLength] = '\0';
          if (hasValidNmeaChecksum(sentence, sentenceLength)) {
            ++lg290pValidNmeaSentences;
            if (!validNmeaAnnounced) {
              validNmeaAnnounced = true;
              Serial.printf("LG290P NMEA verified: %.6s checksum OK\n",
                            sentence);
            }
          }
          sentenceLength = 0;
        } else if (sentenceLength > 0) {
          if (sentenceLength + 1 < sizeof(sentence)) {
            sentence[sentenceLength++] = value;
          } else {
            sentenceLength = 0;
          }
        }
      }
      notifyGnssBytes(buffer, received);
    }
    vTaskDelay(pdMS_TO_TICKS(1));
  }
}

void formatCoordinate(double degrees, bool latitude, char* value,
                      std::size_t valueSize, char* hemisphere) {
  const double absolute = std::fabs(degrees);
  const int wholeDegrees = static_cast<int>(absolute);
  const double minutes = (absolute - wholeDegrees) * 60.0;
  if (latitude) {
    std::snprintf(value, valueSize, "%02d%08.5f", wholeDegrees, minutes);
    *hemisphere = degrees >= 0 ? 'N' : 'S';
  } else {
    std::snprintf(value, valueSize, "%03d%08.5f", wholeDegrees, minutes);
    *hemisphere = degrees >= 0 ? 'E' : 'W';
  }
}

void dummyGnssTask(void*) {
  while (true) {
    const uint32_t now = millis();
    const DummyMode mode = dummyMode;
    // Deliberately synthetic demo coordinates; do not encode a private test site.
    double latitude = 51.0;
    double longitude = 7.0;
    int quality = 4;
    const char* qualityText = "RTK FIX";

    if (mode == DummyMode::kWalk) {
      const double phase = static_cast<double>(now % 120000U) / 120000.0;
      latitude = 50.9998 + phase * (51.0002 - 50.9998);
      longitude = 6.9997 + phase * (7.0003 - 6.9997);
    } else if (mode == DummyMode::kQuality) {
      switch ((now / 10000U) % 3U) {
        case 0:
          quality = 1;
          qualityText = "SINGLE";
          break;
        case 1:
          quality = 5;
          qualityText = "RTK FLOAT";
          break;
        default:
          quality = 4;
          qualityText = "RTK FIX";
          break;
      }
    }

    const uint32_t secondsOfDay = (12U * 3600U + now / 1000U) % 86400U;
    const unsigned hour = secondsOfDay / 3600U;
    const unsigned minute = (secondsOfDay % 3600U) / 60U;
    const unsigned second = secondsOfDay % 60U;
    char utc[16]{};
    const unsigned hundredths = (now % 1000U) / 10U;
    std::snprintf(utc, sizeof(utc), "%02u%02u%02u.%02u", hour, minute,
                  second, hundredths);

    char latitudeValue[20]{};
    char longitudeValue[20]{};
    char latitudeHemisphere = 'N';
    char longitudeHemisphere = 'E';
    formatCoordinate(latitude, true, latitudeValue, sizeof(latitudeValue),
                     &latitudeHemisphere);
    formatCoordinate(longitude, false, longitudeValue,
                     sizeof(longitudeValue), &longitudeHemisphere);

    char body[170]{};
    std::snprintf(body, sizeof(body),
                  "GNGGA,%s,%s,%c,%s,%c,%d,24,0.70,88.500,M,46.000,M,0.5,"
                  "0000",
                  utc, latitudeValue, latitudeHemisphere, longitudeValue,
                  longitudeHemisphere, quality);
    notifyNmeaBody(body);

    std::snprintf(body, sizeof(body),
                  "GNRMC,%s,A,%s,%c,%s,%c,0.80,42.0,100826,,,A", utc,
                  latitudeValue, latitudeHemisphere, longitudeValue,
                  longitudeHemisphere);
    notifyNmeaBody(body);

    std::snprintf(body, sizeof(body),
                  "GNGST,%s,0.012,0.018,0.014,0.0,0.010,0.010,0.025", utc);
    notifyNmeaBody(body);

    std::snprintf(body, sizeof(body), "PQTMTXT,1,%s", qualityText);
    notifyNmeaBody(body);

    vTaskDelay(pdMS_TO_TICKS(200));
  }
}
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
void loop() { delay(1000); }

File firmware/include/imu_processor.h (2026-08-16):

#pragma once

#include <cstdint>

namespace kataster {

struct ImuSample {
  float accelerationXG = 0.0F;
  float accelerationYG = 0.0F;
  float accelerationZG = 1.0F;
  float gyroXDps = 0.0F;
  float gyroYDps = 0.0F;
  float gyroZDps = 0.0F;
  uint32_t timestampMs = 0;
};

struct ImuCalibration {
  float gyroBiasXDps = 0.0F;
  float gyroBiasYDps = 0.0F;
  float gyroBiasZDps = 0.0F;
  float mountingRollDegrees = 0.0F;
  float mountingPitchDegrees = 0.0F;
  float accelerationReferenceG = 1.0F;
  // Direction of the housing marker in the sensor tilt plane. The angle is
  // atan2(roll, pitch), measured while the pole top is tilted toward the
  // marker/operator. -90 degrees matches the documented +Y marker mounting.
  float markerDirectionDegrees = -90.0F;
  bool valid = false;
  bool markerValid = false;
};

enum class ImuCalibrationState : uint8_t {
  kRequired,
  kCollectingLevel,
  kCollectingMarker,
  kReady,
};

struct ImuReading {
  float rollDegrees = 0.0F;
  float pitchDegrees = 0.0F;
  float totalTiltDegrees = 0.0F;
  float markerDirectionDegrees = -90.0F;
  float accelerationMagnitudeG = 1.0F;
  float angularRateDps = 0.0F;
  bool moving = true;
  bool level = false;
  bool measurementReady = false;
  bool calibrated = false;
  bool directionCalibrated = false;
  uint16_t calibrationSamples = 0;
  uint32_t stableMilliseconds = 0;
  uint32_t readySequence = 0;
  ImuCalibrationState calibrationState = ImuCalibrationState::kRequired;
  uint32_t timestampMs = 0;
};

class ImuProcessor {
 public:
  static constexpr float kLevelThresholdDegrees = 0.5F;
  static constexpr uint32_t kReadyHoldMilliseconds = 400;
  static constexpr uint16_t kCalibrationSampleCount = 125;
  static constexpr uint16_t kMarkerCalibrationSampleCount = 30;

  ImuReading update(const ImuSample& sample);
  void beginCalibration();
  bool beginDirectionCalibration();
  void resetCalibration();
  void setCalibration(const ImuCalibration& calibration);

  const ImuCalibration& calibration() const { return calibration_; }
  const ImuReading& reading() const { return reading_; }
  bool takeCalibrationCompleted();

 private:
  static float radiansToDegrees(float radians);
  static float vectorMagnitude(float x, float y, float z);
  void resetCalibrationSums();

  ImuCalibration calibration_;
  ImuReading reading_;
  bool filterInitialized_ = false;
  bool hasTimestamp_ = false;
  bool calibrationCompleted_ = false;
  uint32_t previousTimestampMs_ = 0;
  uint32_t stableSinceMs_ = 0;
  uint32_t readySequence_ = 0;
  float filteredRollDegrees_ = 0.0F;
  float filteredPitchDegrees_ = 0.0F;

  uint16_t calibrationSamples_ = 0;
  float calibrationGyroXSum_ = 0.0F;
  float calibrationGyroYSum_ = 0.0F;
  float calibrationGyroZSum_ = 0.0F;
  float calibrationRollSum_ = 0.0F;
  float calibrationPitchSum_ = 0.0F;
  float calibrationAccelerationMagnitudeSum_ = 0.0F;
  float markerPitchSum_ = 0.0F;
  float markerRollSum_ = 0.0F;
  uint8_t markerRejectedSamples_ = 0;
};

const char* calibrationStateName(ImuCalibrationState state);

}  // namespace kataster
